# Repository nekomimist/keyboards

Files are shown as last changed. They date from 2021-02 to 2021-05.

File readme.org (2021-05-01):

* Nekomimist's keyboards

** nekonos0 (nekonos prototype)

- Name :: キ1-r0.0 (nakonos0 evt)
- Board :: [[https://e3w2q.github.io/9/][SU120]]を利用した手作り
- Motivation :: 自分の好きなレイアウトを探るためのプロトタイプ
- Firmware :: [[https://github.com/nekomimist/qmk_firmware/tree/nekomimist/keyboards/e3w2q/su120/rev1]]
- Photo :: [[https://twitter.com/nekomimist/status/1332611166024069120][twitter]]

** nekonos1 rev0.1

- Name :: キ1-r0.1 (nekonos1 dvt)
- Board :: 自作
- Board Manufacuter :: Elecrow
- Motivation :: nekonos0を自設計基板で動かすこと
- Firmware :: [[https://github.com/nekomimist/qmk_firmware/tree/nekomimist/keyboards/nkns1/rev01]]
- Photo :: [[https://twitter.com/nekomimist/status/1341686424458805250][twitter]]

** nekonos0r (nekonos prototype-r)

- Name :: キ0-r0.0r (nakonos0r)
- Board :: [[https://e3w2q.github.io/9/][SU120]]を利用した手作り (キ0-r0.0からの一部改造)
- Motivation :: ロータリーエンコーダの使用感確認のため
- Firmware :: [[https://github.com/nekomimist/qmk_firmware/tree/nekomimist/keyboards/e3w2q/su120/rev1_2knob]]
- Photo :: [[https://twitter.com/nekomimist/status/1352829978916704256][twitter]]

** nekonos1 rev0.2

- Name :: キ1-r0.2 (nekonos1)
- Board :: 自作
- Board Manufacuter :: JLCPCB
- Motivation :: ロータリーエンコーダ対応とunderglowとリセットの位置の改善
- Firmware :: [[https://github.com/nekomimist/qmk_firmware/tree/nekomimist/keyboards/nkns1/rev02]]
- Photo :: [[https://twitter.com/nekomimist/status/1358013858917412865][twitter]]

** nekonote0 

- Name :: キ2-r0.0 (nekonote0)
- Board :: [[https://e3w2q.github.io/11/][te96]]を利用した手作り
- Motivation :: 狭ピッチ(18x16mm)一体型Ortholinearキーボードのプロトタイピング
- Firmware :: [[https://github.com/nekomimist/qmk_firmware/tree/nekomimist/keyboards/nknt0]]
- Photo :: [[https://twitter.com/nekomimist/status/1349289225011662850][twitter]]

** nekomacropad0

- Name :: キ3-r0.0 (nekomacropad0)
- Board :: SU120を利用した手作り
- Motivation :: 3Dプリンタを利用して余白ちょっと大き目のケースを試作する
- Motivation :: SU120でProMicroを裏面につけてみる
- Motivation :: remapでキーカスタマイズできるようにする
- Firmware :: https://github.com/nekomimist/qmk_firmware/tree/nekomimist/keyboards/nkmp0
- Case :: いつか整理して上げる
- Photo :: [[https://twitter.com/nekomimist/status/1388371816700284932][twitter]] [[https://twitter.com/nekomimist/status/1388373248652443649][twitter]]

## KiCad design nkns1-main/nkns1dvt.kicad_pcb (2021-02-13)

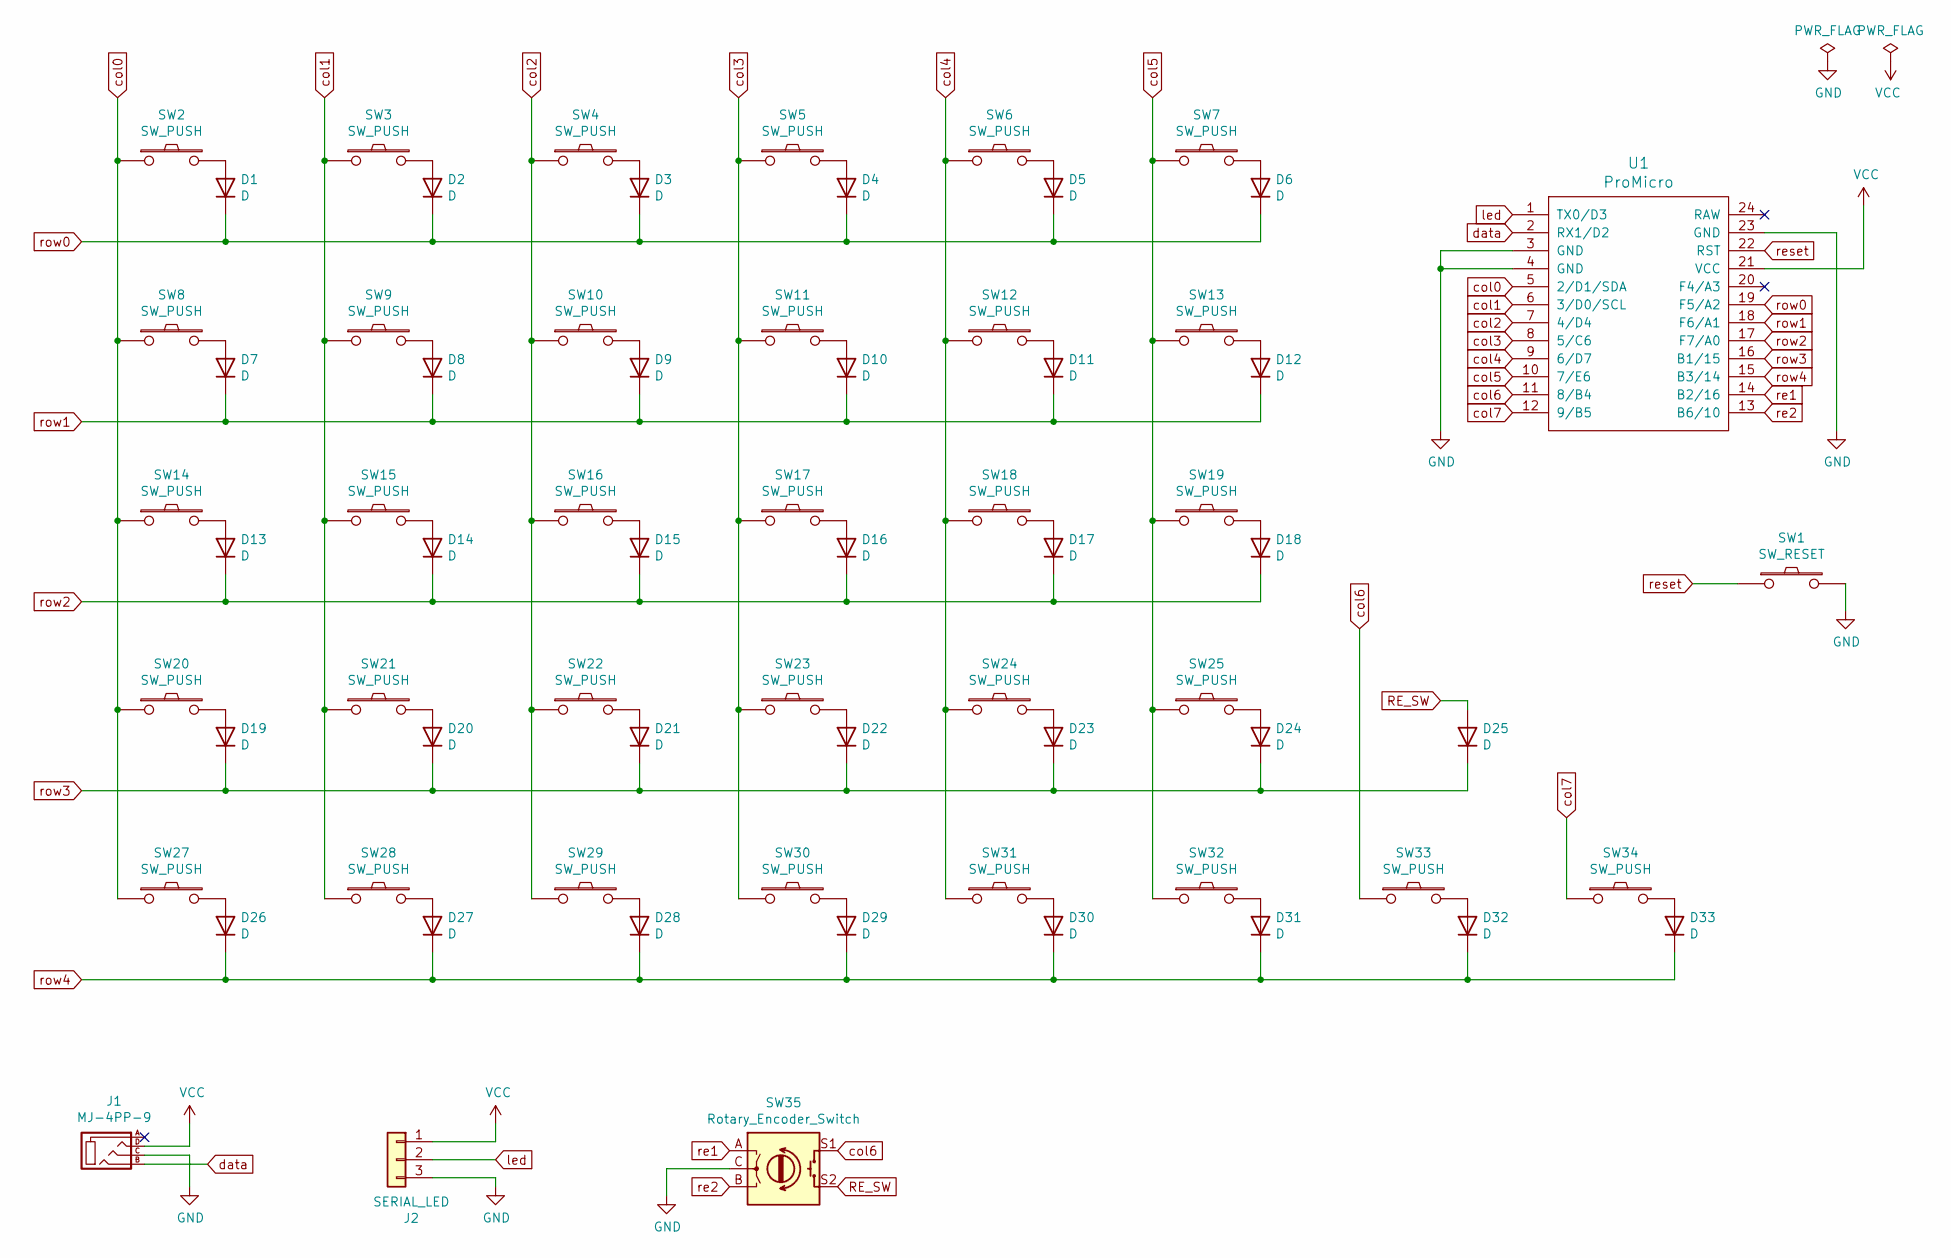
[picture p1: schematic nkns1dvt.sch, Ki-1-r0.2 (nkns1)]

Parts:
D1, D2, D3, D4, D5, D6, D7, D8, D9, D10, D11, D12, D13, D14, D15, D16, D17, D18, D19, D20, D21, D22, D23, D24, D25, D26, D27, D28, D29, D30, D31, D32, D33: D; D3_TH_SMD
J1: MJ-4PP-9
J2: SERIAL_LED; StripLED_rev
SW1: SW_RESET; ResetSW
SW2, SW3, SW4, SW5, SW6, SW7, SW8, SW9, SW10, SW11, SW12, SW13, SW14, SW15, SW16, SW17, SW18, SW19, SW20, SW21, SW22, SW23, SW24, SW25, SW27, SW28, SW29, SW30, SW31, SW32, SW33, SW34: SW_PUSH; CherryMX_MidHeight_Hotswap
SW35: Rotary_Encoder_Switch; RotaryEncoder_Alps_EC12E-Switch_Vertical_H20mm
U1: ProMicro; ProMicro_v2

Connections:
GND: J1.C, J2.3, SW1.2, SW35.C, U1.3 (GND), U1.4 (GND), U1.23 (GND)
unnamed: D1.2 (A), SW2.2
unnamed: D2.2 (A), SW3.2
unnamed: D3.2 (A), SW4.2
unnamed: D4.2 (A), SW5.2
unnamed: D5.2 (A), SW6.2
unnamed: D6.2 (A), SW7.2
unnamed: D7.2 (A), SW8.2
unnamed: D8.2 (A), SW9.2
unnamed: D9.2 (A), SW10.2
unnamed: D10.2 (A), SW11.2
unnamed: D11.2 (A), SW12.2
unnamed: D12.2 (A), SW13.2
unnamed: D13.2 (A), SW14.2
unnamed: D14.2 (A), SW15.2
unnamed: D15.2 (A), SW16.2
unnamed: D16.2 (A), SW17.2
unnamed: D17.2 (A), SW18.2
unnamed: D18.2 (A), SW19.2
unnamed: D19.2 (A), SW20.2
unnamed: D20.2 (A), SW21.2
unnamed: D21.2 (A), SW22.2
unnamed: D22.2 (A), SW23.2
unnamed: D23.2 (A), SW24.2
unnamed: D24.2 (A), SW25.2
unnamed: D26.2 (A), SW27.2
unnamed: D27.2 (A), SW28.2
unnamed: D28.2 (A), SW29.2
unnamed: D29.2 (A), SW30.2
unnamed: D30.2 (A), SW31.2
unnamed: D31.2 (A), SW32.2
unnamed: D32.2 (A), SW33.2
unnamed: D33.2 (A), SW34.2
RE_SW: D25.2 (A), SW35.S2
VCC: J1.D, J2.1, U1.21 (VCC)
col0: SW2.1, SW8.1, SW14.1, SW20.1, SW27.1, U1.5 (2/D1/SDA)
col1: SW3.1, SW9.1, SW15.1, SW21.1, SW28.1, U1.6 (3/D0/SCL)
col2: SW4.1, SW10.1, SW16.1, SW22.1, SW29.1, U1.7 (4/D4)
col3: SW5.1, SW11.1, SW17.1, SW23.1, SW30.1, U1.8 (5/C6)
col4: SW6.1, SW12.1, SW18.1, SW24.1, SW31.1, U1.9 (6/D7)
col5: SW7.1, SW13.1, SW19.1, SW25.1, SW32.1, U1.10 (7/E6)
col6: SW33.1, SW35.S1, U1.11 (8/B4)
col7: SW34.1, U1.12 (9/B5)
data: J1.B, U1.2 (RX1/D2)
led: J2.2, U1.1 (TX0/D3)
re1: SW35.A, U1.14 (B2/16)
re2: SW35.B, U1.13 (B6/10)
reset: SW1.1, U1.22 (RST)
row0: D1.1 (K), D2.1 (K), D3.1 (K), D4.1 (K), D5.1 (K), D6.1 (K), U1.19 (F5/A2)
row1: D7.1 (K), D8.1 (K), D9.1 (K), D10.1 (K), D11.1 (K), D12.1 (K), U1.18 (F6/A1)
row2: D13.1 (K), D14.1 (K), D15.1 (K), D16.1 (K), D17.1 (K), D18.1 (K), U1.17 (F7/A0)
row3: D19.1 (K), D20.1 (K), D21.1 (K), D22.1 (K), D23.1 (K), D24.1 (K), D25.1 (K), U1.16 (B1/15)
row4: D26.1 (K), D27.1 (K), D28.1 (K), D29.1 (K), D30.1 (K), D31.1 (K), D32.1 (K), D33.1 (K), U1.15 (B3/14)

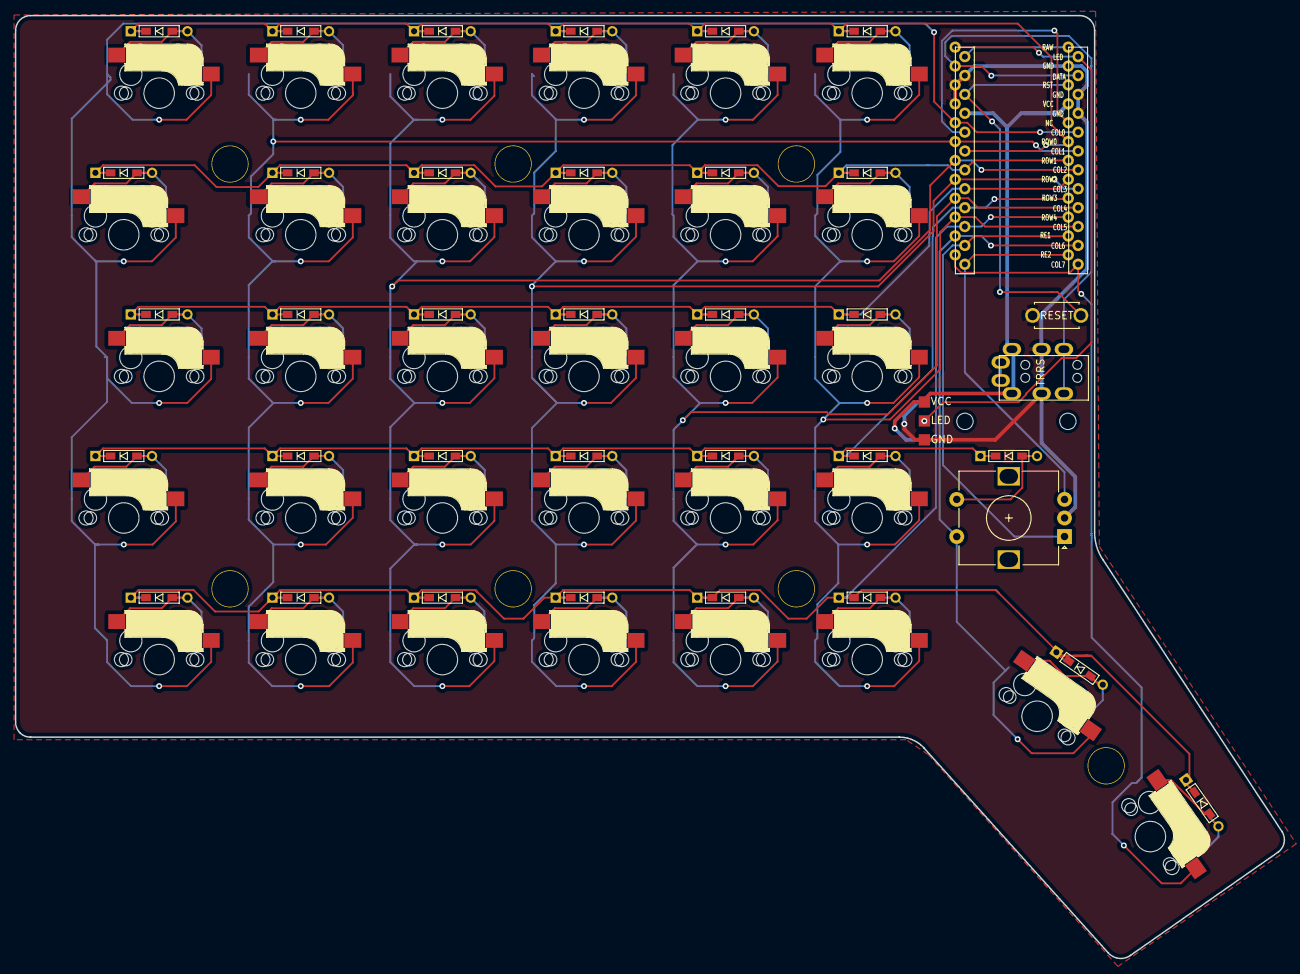
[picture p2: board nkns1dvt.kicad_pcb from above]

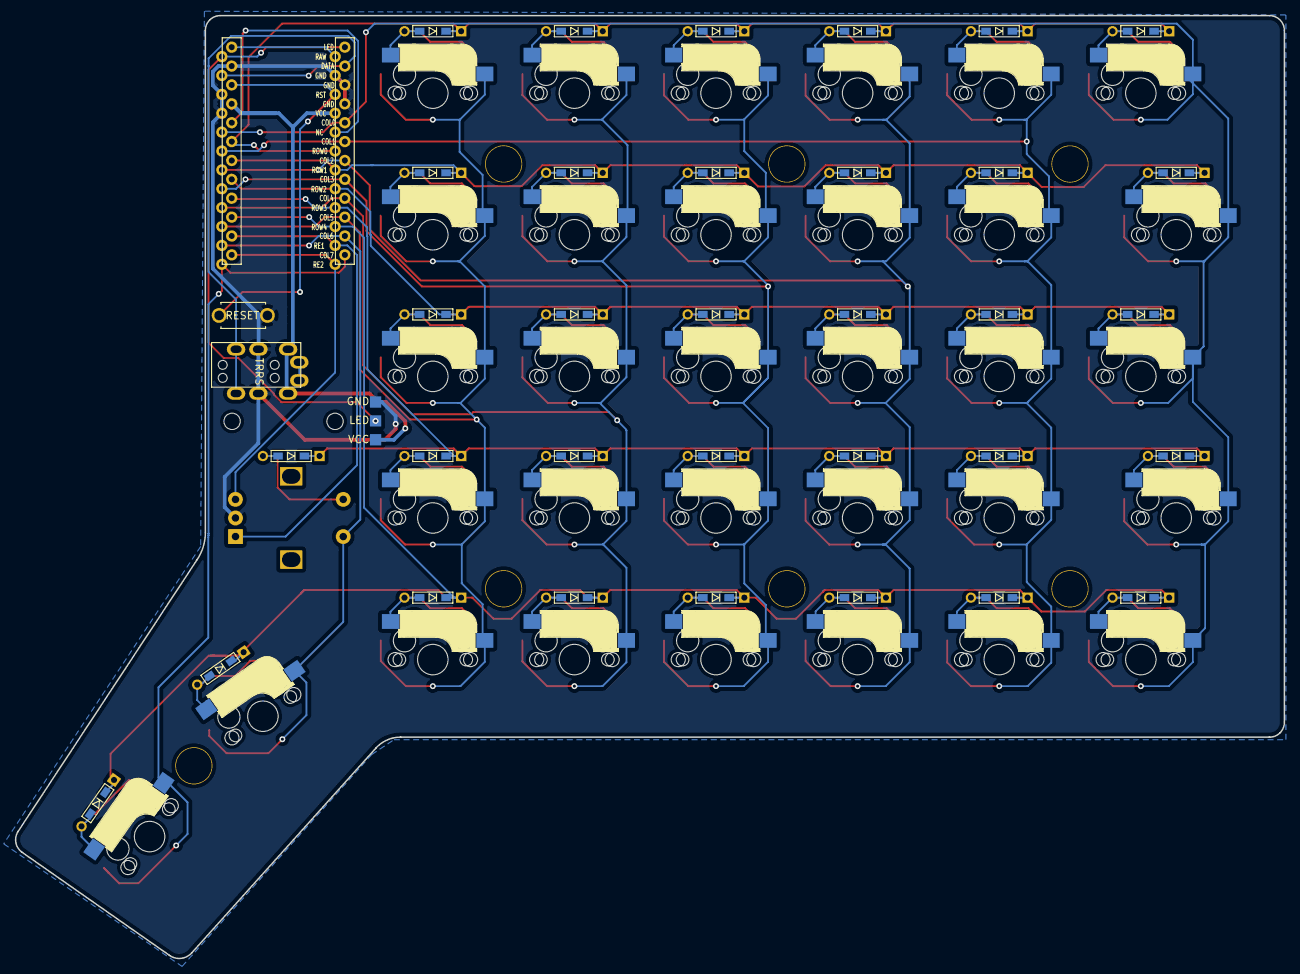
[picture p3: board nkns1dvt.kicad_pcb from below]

Board: 2 copper layers, 170.7 x 126.8 mm, 79 parts (2 on the bottom side), 53 nets.

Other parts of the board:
Hole1, Hole2, Hole3, Hole4, Hole5, Hole6, Hole7: HOLE
Hole M1, Hole M2: MountingHole_2.2mm_M2

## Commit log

2020-11-07 Change promicro footprint Change edge layer
    [nkns1dvt.kicad_pcb]
2020-11-08 Modify LED. Add GND/VCC route.
    [nkns1dvt.kicad_pcb, nkns1dvt.sch]
2020-11-09 Change to reversible.
    [nkns1dvt.kicad_pcb, nkns1dvt.sch, topplate-for-reversible.dxf]
2020-11-12 Add wire. Add Mounting hole for ProMicro Area Plate.
    [nkns1dvt.kicad_pcb]
2020-11-12 Add beta-GND
    [nkns1dvt.kicad_pcb]
2020-11-14 Modify board name.
    [nkns1dvt.sch]
2020-11-29 Change diode footprints
    [nkns1dvt.kicad_pcb, nkns1dvt.sch]
2020-11-29 Pro Micro横の基板幅を2mmほど小さくした
    [nkns1dvt.kicad_pcb]
2020-12-24 nkns1dvt rev.0.1
    [nkns1dvt.kicad_pcb]
2021-02-13 nkns1 rev.0.2
    * Change row0-row5 port.
    * Add rotary encoder.
    [nkns1dvt.kicad_pcb, nkns1dvt.sch]
2021-02-13 Modify directory structure
    [nkns1dvt.kicad_pcb, nkns1dvt.sch]
2021-02-13 Add plate data for nkns1 r0.1/r0.2
    [nkns1dvt-plate.kicad_pcb]
2021-02-13 Modify to plated key holes (nkns1-plate)
    [nkns1dvt-plate.kicad_pcb]
2021-02-13 Add my footprint library
2021-02-13 Add nekonos prototype & nekonote0's plate data
